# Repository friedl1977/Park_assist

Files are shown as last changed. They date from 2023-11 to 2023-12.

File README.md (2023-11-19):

# Park_assist

A Particle project named Park_assist

## Welcome to your project!

Every new Particle project is composed of 3 important elements that you'll see have been created in your project directory for Park_assist.

#### ```/src``` folder:  
This is the source folder that contains the firmware files for your project. It should *not* be renamed. 
Anything that is in this folder when you compile your project will be sent to our compile service and compiled into a firmware binary for the Particle device that you have targeted.

If your application contains multiple files, they should all be included in the `src` folder. If your firmware depends on Particle libraries, those dependencies are specified in the `project.properties` file referenced below.

#### ```.ino``` file:
This file is the firmware that will run as the primary application on your Particle device. It contains a `setup()` and `loop()` function, and can be written in Wiring or C/C++. For more information about using the Particle firmware API to create firmware for your Particle device, refer to the [Firmware Reference](https://docs.particle.io/reference/firmware/) section of the Particle documentation.

#### ```project.properties``` file:  
This is the file that specifies the name and version number of the libraries that your project depends on. Dependencies are added automatically to your `project.properties` file when you add a library to a project using the `particle library add` command in the CLI or add a library in the Desktop IDE.

## Adding additional files to your project

#### Projects with multiple sources
If you would like add additional files to your application, they should be added to the `/src` folder. All files in the `/src` folder will be sent to the Particle Cloud to produce a compiled binary.

#### Projects with external libraries
If your project includes a library that has not been registered in the Particle libraries system, you should create a new folder named `/lib/<libraryname>/src` under `/<project dir>` and add the `.h`, `.cpp` & `library.properties` files for your library there. Read the [Firmware Libraries guide](https://docs.particle.io/guide/tools-and-features/libraries/) for more details on how to develop libraries. Note that all contents of the `/lib` folder and subfolders will also be sent to the Cloud for compilation.

## Compiling your project

When you're ready to compile your project, make sure you have the correct Particle device target selected and run `particle compile <platform>` in the CLI or click the Compile button in the Desktop IDE. The following files in your project folder will be sent to the compile service:

- Everything in the `/src` folder, including your `.ino` application file
- The `project.properties` file for your project
- Any libraries stored under `lib/<libraryname>/src`

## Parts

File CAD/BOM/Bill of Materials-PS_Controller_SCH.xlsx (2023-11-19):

Comment | Description | Designator | Quantity | Manufacturer
885012207072 | WCAP-CSGP Multilayer Ceramic Chip Capacitor, General Purpose, size 0805, X7R, 100nF, 25VDC | C1 | 1 | Wurth Elektronik
885012107014 | WCAP-CSGP Multilayer Ceramic Chip Capacitor, General Purpose, size 0805, X5R, 10µF, 16VDC | C2, C3 | 2 | Wurth Elektronik
885012006021 | WCAP-CSGP Multilayer Ceramic Chip Capacitor, General Purpose, size 0603, NP0, 47pF, 16VDC | C4 | 1 | Wurth Elektronik
885012206071 | WCAP-CSGP Multilayer Ceramic Chip Capacitor, General Purpose, size 0603, X7R, 100nF, 25VDC | C5 | 1 | Wurth Elektronik
885012106012 | WCAP-CSGP Multilayer Ceramic Chip Capacitor, General Purpose, size 0603, X5R, 4.7µF, 10VDC | C6 | 1 | Wurth Elektronik
150060BS73220 | WL-SMCC SMD Mono-color Chip LED Compact, size 0603, Blue, 3.2V, 120deg | D1, D2 | 2 | Wurth Elektronik
SF-3812TM200T-2 | Fuse | F1 | 1
ISL80102IRAJZ-TK | Integrated Circuit | IC1 | 1 | Intersil
VL53L1CXV0FY_1 | Integrated Circuit | IC2 | 1 | ST
691401710003B | WR-TBL Series 401B Horizontal Entry, Through Hole, pitch 5mm, 3p | J1 | 1 | Wurth Elektronik
691401710002B | WR-TBL Series 401B Horizontal Entry, Through Hole, pitch 5mm, 2p | J2, J3 | 2 | Wurth Elektronik
61301611121 |  | P1 | 1 | Wurth Elektronik
61301211121 |  | P2 | 1 | Wurth Elektronik
RK73H1JTTDD2201F | Thick Film Resistors 1/10watt 2.2kΩ 1% | R1, R9 | 2 | KOA
RK73H1JTTD1002D | Res Thick Film 0603 10KΩ 0.5% 0.1W(1/10W) ±100ppm/C Pad SMD Automotive T/R | R2, R5, R6, R7 | 4 | KOA
RK73H1JTTD2401D | Res Thick Film 0603 2.4kΩ 0.5% 0.1W(1/10W) ±100ppm/C Pad SMD Automotive T/R | R3, R4 | 2 | KOA
RK73H1JTTDD6492F | Thick Film Resistors - SMD 1/10watts 64.9Ω | R8 | 1 | KOA
SolderBride_0.2 | OPEN Solder brige 3mm x1.5mm | R11 | DNP
820412711 | 820412711 Disk Varistor HighSurge WE-VD | RV1 | 1 | Wurth Elektronik
RCUCTE | RSmall PC test point | TP1 | 1 | KOA
RAC10E-05SK/277 | 10W AC/DC-CONVERTER 'POWERLINE' | U1 | 1 | RECOM

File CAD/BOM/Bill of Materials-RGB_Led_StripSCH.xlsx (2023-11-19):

Comment | Description | Designator | Quantity | Manufacturer
150121M173000 | 150121M173000 WL-SFCW SMT Full-color Chip LED waterclear | D1, D2, D3, D4, D5, D6, D7, D8, D9, D10, D11, D12, D13, D14, D15, D16 | 16 | Wurth Elektronik
691401710002B | WR-TBL Series 401B Horizontal Entry, Through Hole, pitch 5mm, 2p | J1 | 1 | Wurth Elektronik
691401710003B | WR-TBL Series 401B Horizontal Entry, Through Hole, pitch 5mm, 3p | J2 | 1 | Wurth Elektronik
BSS138P,215 | BSS138P Series 60 V 1.6 Ohm 350 mW 0.72 nC N-Channel SMT TrenchMOS FET - SOT-23 | Q1, Q2, Q3 | 3 | Nexperia
RK73H1JLTD3300F | Thick Film Resistors 1/10watts 330ohms 1% | R1, R2, R3, R4, R5, R6, R7, R8, R9, R10, R11, R12 | 12 | KOA

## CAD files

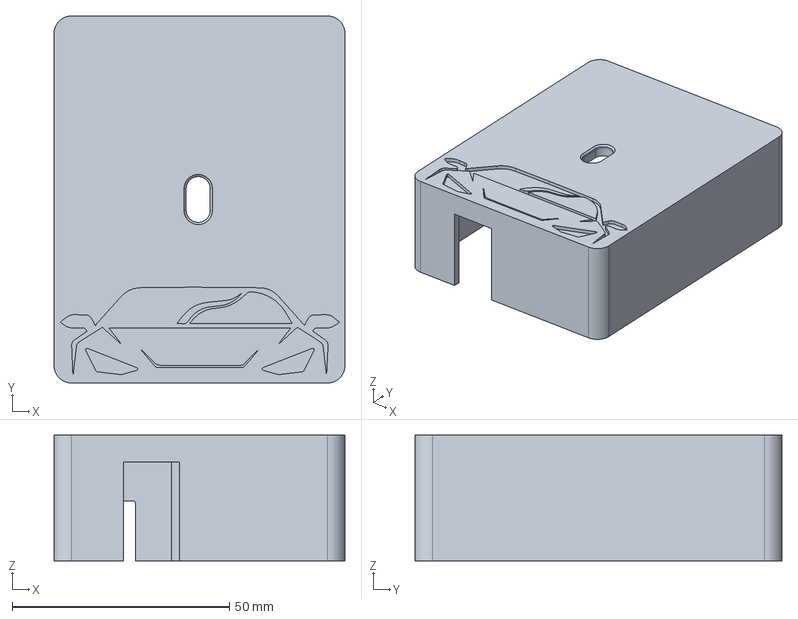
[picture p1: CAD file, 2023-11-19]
CAD/3D_Prints/Controller_Base.step
67.0 x 84.5 x 29.0 mm

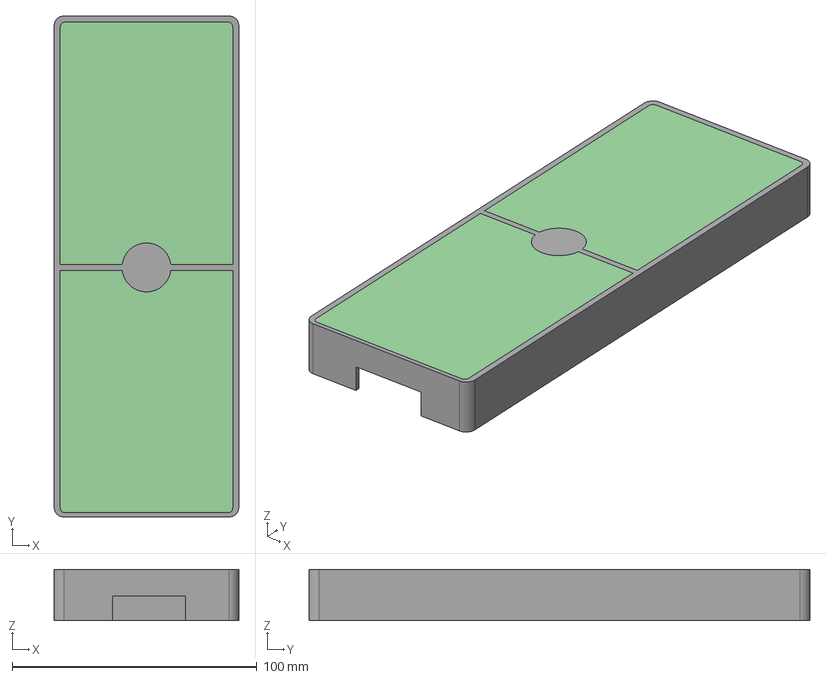
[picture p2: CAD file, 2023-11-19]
CAD/3D_Prints/RGB Panel_Lid.step
75.5 x 204.8 x 21.0 mm

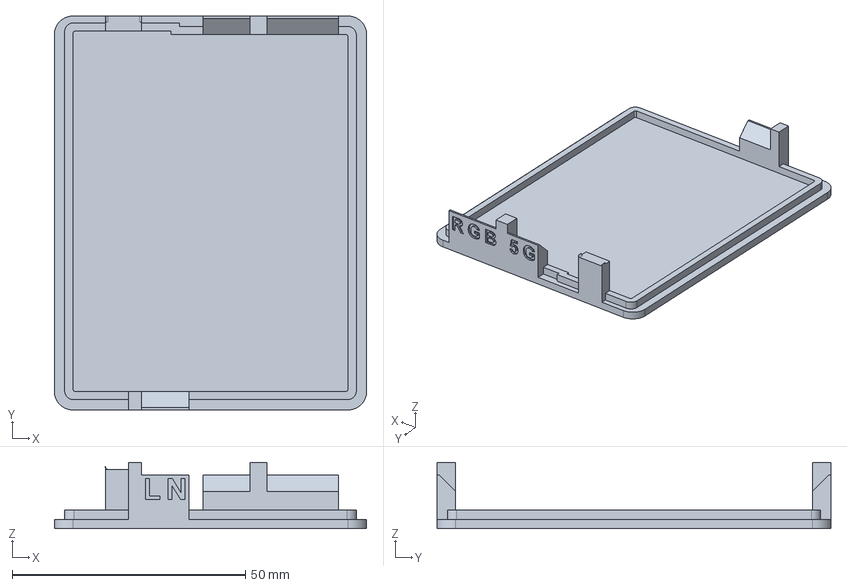
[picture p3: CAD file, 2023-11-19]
CAD/3D_Prints/Controller_Lid.step
67.0 x 84.5 x 14.2 mm

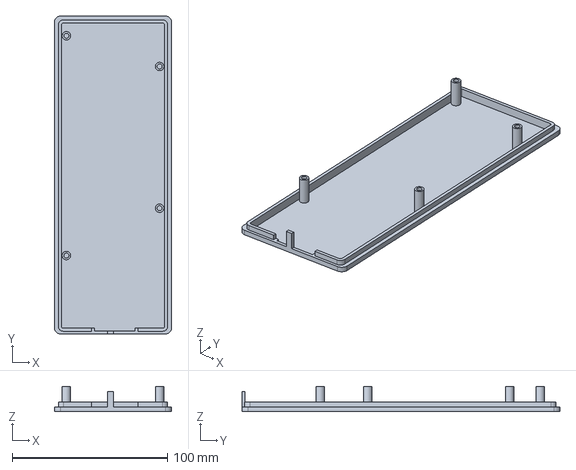
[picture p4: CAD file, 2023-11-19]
CAD/3D_Prints/RGB Panel_Base.step
75.5 x 204.8 x 16.1 mm

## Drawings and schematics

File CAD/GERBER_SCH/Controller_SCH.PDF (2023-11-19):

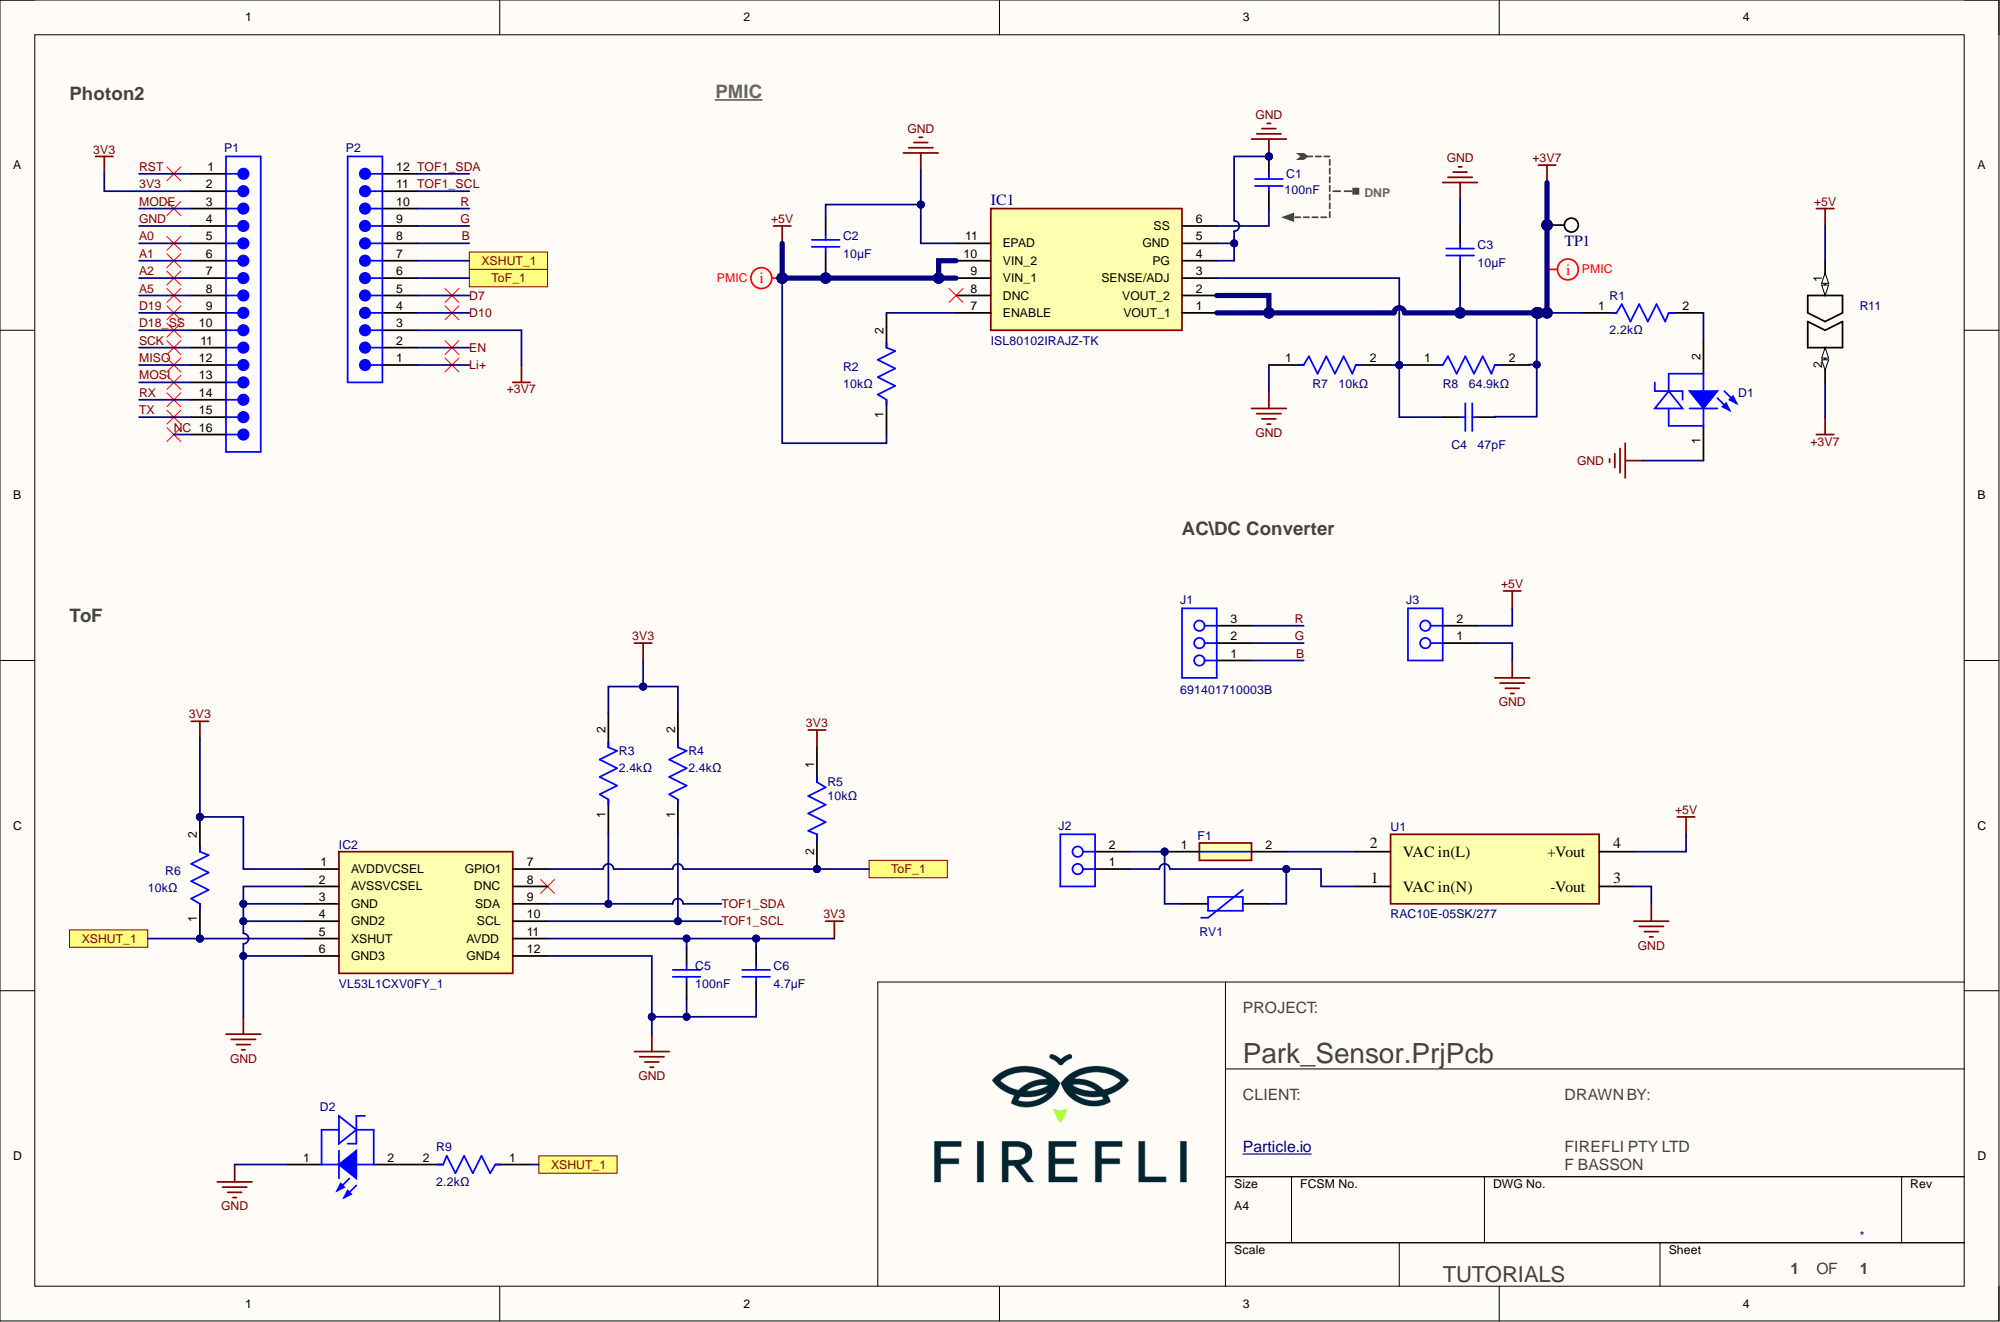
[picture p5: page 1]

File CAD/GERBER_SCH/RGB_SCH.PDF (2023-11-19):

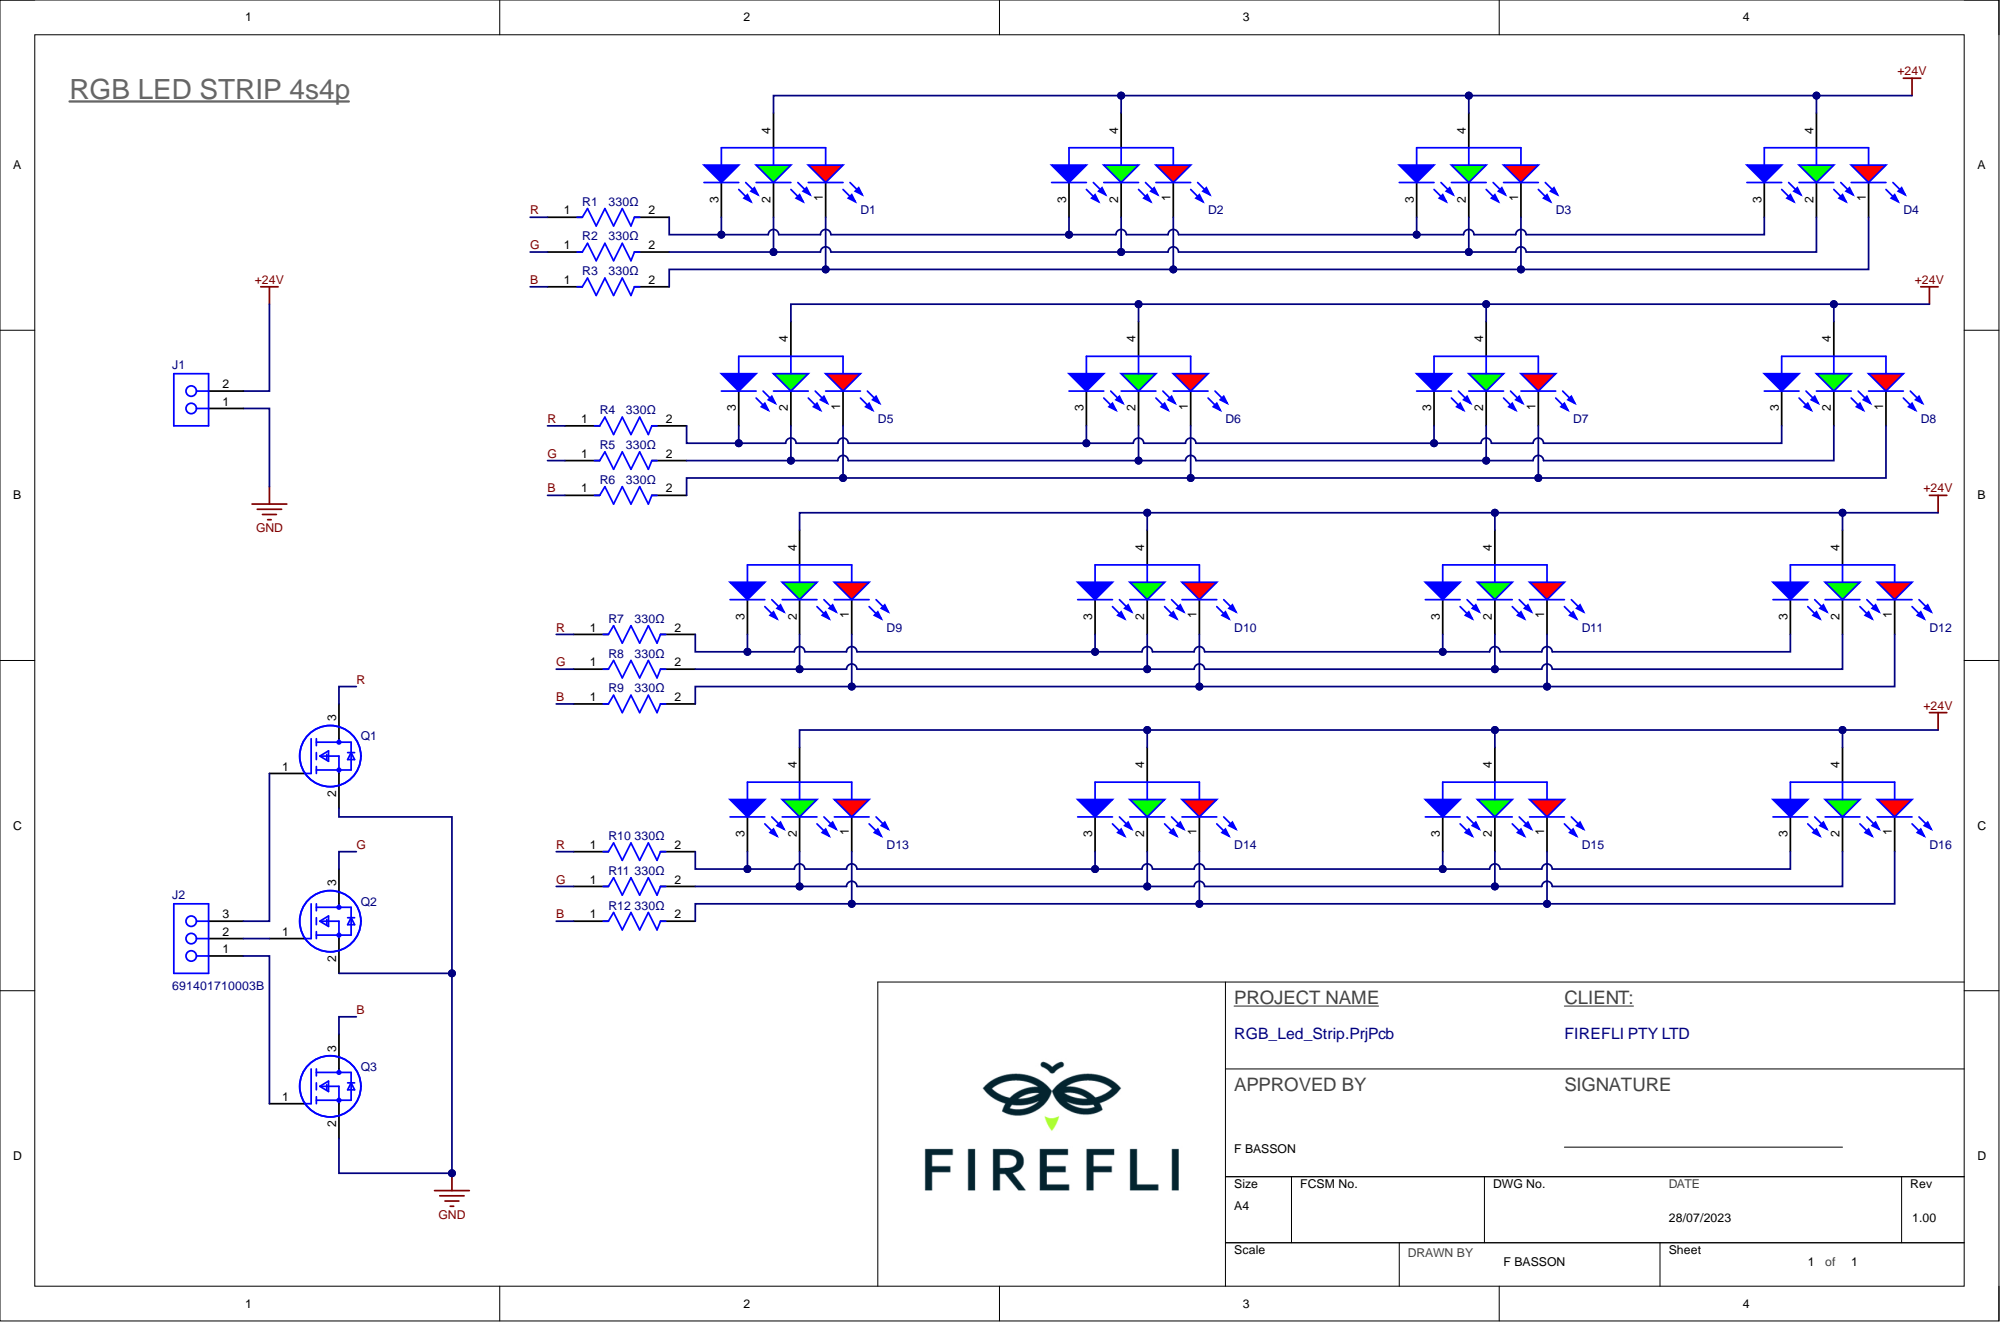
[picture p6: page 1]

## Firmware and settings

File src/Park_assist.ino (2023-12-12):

// PROJECT      :   Parking Sensor
// Designed by  :   FireFli
// REV          :   1.00
// Date         :   December 2023

#include "../lib/SparkFun_VL53L1X_Arduino_Library/src/SparkFun_VL53L1X.h"
#include <Wire.h>

#define Red_Pin D2
#define Green_Pin D3
#define Blue_Pin D4

//Set up dintance thresholds (mm)

int far = 1500;
int near = 750;
int stop = 300;

int Distance;

int ledState = LOW;  // ledState used to set the LED

unsigned long previousMillis = 0;
unsigned interval = 0;


VL53L1X sensor;

void setup() {
    
    Wire.begin();
    delay(200);
    
    pinMode(Red_Pin, OUTPUT);
    pinMode(Green_Pin, OUTPUT);
    pinMode(Blue_Pin, OUTPUT);
    
    digitalWrite (Red_Pin, HIGH); 
    digitalWrite (Blue_Pin, LOW);
    digitalWrite (Green_Pin, LOW);
    
    delay(500);
    
    digitalWrite (Red_Pin, LOW); 
    digitalWrite (Blue_Pin, HIGH);
    digitalWrite (Green_Pin, LOW);
    
    delay(500);
    
    digitalWrite (Red_Pin, LOW); 
    digitalWrite (Blue_Pin, LOW);
    digitalWrite (Green_Pin, HIGH);
    
    delay(500);
    
    digitalWrite (Red_Pin, LOW); 
    digitalWrite (Blue_Pin, LOW);
    digitalWrite (Green_Pin, LOW);
    
    delay(500);
    
}


void ToF1() {
    
    Wire.setClock(400000);                                          // use 400 kHz I2C
    sensor.init(0x29);
    
    if (!sensor.init(0x29)) {
        Particle.publish("Could not find a valid ToF1 on bus 0, check wiring!");            //  Debug
        while (1);                                                                          //  Debug
            } //else { Particle.publish("Tof1 Device OK");                                  //  Debug
        //}

    sensor.setDistanceMode(VL53L1X::Long);
    sensor.setMeasurementTimingBudget(50000);
    sensor.startContinuous(50);                                                             // timing budget

    //Particle.publish("ToF1: " + String(sensor.read()) + "mm", PRIVATE);                   // Publish Results in mm
    if (sensor.timeoutOccurred()) { Serial.print(" TIMEOUT"); }

    Distance = sensor.read();
    
}

void LED_PANEL() {
    
    if (Distance >= (far)) {
        digitalWrite (Red_Pin, LOW); 
        digitalWrite (Blue_Pin, LOW);
        digitalWrite (Green_Pin, HIGH);
    
    } else if (Distance <= (far) && Distance >= (near)) {
        interval = 250;
        FlashYellow();

    } else if (Distance < (near) && Distance >= (stop)) {
        interval = 100;
        FlashRed();
        
    } else if (Distance <= (stop)) {

        digitalWrite (Red_Pin, HIGH); 
        digitalWrite (Blue_Pin, LOW);
        digitalWrite (Green_Pin, LOW);
    }
}


void FlashYellow() {
    
    unsigned long currentMillis = millis();

    if (currentMillis - previousMillis >= interval) {
        previousMillis = currentMillis;

    if (ledState == LOW) {
        
        digitalWrite (Red_Pin, HIGH); 
        digitalWrite (Blue_Pin, LOW);
        digitalWrite (Green_Pin, HIGH);
        
        ledState = HIGH;
        
    } else {
            
            digitalWrite (Red_Pin, LOW); 
            digitalWrite (Blue_Pin, LOW);
            digitalWrite (Green_Pin, LOW);
            
            ledState = LOW;
            }
    }
}

void FlashRed() {
    
    unsigned long currentMillis = millis();

    if (currentMillis - previousMillis >= interval) {
        previousMillis = currentMillis;

    if (ledState == LOW) {
        
        digitalWrite (Red_Pin, HIGH); 
        digitalWrite (Blue_Pin, LOW);
        digitalWrite (Green_Pin, LOW);
        
        ledState = HIGH;
        
    } else {
            
            digitalWrite (Red_Pin, LOW); 
            digitalWrite (Blue_Pin, LOW);
            digitalWrite (Green_Pin, LOW);
            
            ledState = LOW;
            }
    }
}

void loop() {
    
    ToF1();
    LED_PANEL();
    
    delay(100);
}

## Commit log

2023-11-19 New Project - Initial Commit
    [Bill of Materials-PS_Controller_SCH.xlsx, Bill of Materials-RGB_Led_StripSCH.xlsx]
2023-11-19 STEP files added
    [Controller_Base.step, Controller_Lid.step, RGB Panel_Base.step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]
